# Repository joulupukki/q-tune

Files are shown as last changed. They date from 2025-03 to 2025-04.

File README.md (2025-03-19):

# Q-Tune Chromatic Tuner
This is an in-progress project with the goal of creating a fully open-source chromatic tuner in a standard pedal enclosure for use on pedalboards and based on the ESP32 MCU.

The project uses the Q DSP Library for frequency detection and LVGL 9 for the graphical user interface.

The project now uses a [Waveshare ESP32-S3 Touch 2.8" 240x320](https://www.waveshare.com/product/mcu-tools/development-boards/esp32/esp32-s3-touch-lcd-2.8.htm?sku=27690) screen because of its clean cover glass that's already attached. It helps make a very professional look in a guitar pedal. Currently the capacitive touch isn't being used.

The project first used a Heltec ESP32-S3 with a smaller display, graduated to the Cheap Yellow Display (ESP32-2432S028R/ESP32-WROOM-32), and is now using the Waveshare.

## Setup

1. Install Visual Studio Code
2. Install the Visual Studio Code ESP-IDF extension
3. Configure the ESP-IDF extension by using the express or advanced mode
    - Be sure to choose **v5.3** as the version of ESP-IDF to use
    - You may need to use advanced mode to be able to select the correct location for python3
    - If pip error, navigate to: C:\Espressif\tools\idf-python\3.11.2> and run: python -m ensurepip --upgrade
4. Make sure you have `git` installed
5. Clone this github project
6. From a terminal go into the project and do this:
    ```
    git submodule update --init --recursive
    ```
7. Open the `q-tune` folder in VS Code
8. Set your ESP32 target (esp32s3)
    - Open the Command Palette (Command+Shift+P on a Mac) and select `ESP-IDF: Set Espressif Device Target`
    - Select `esp32s3`
    - Select the `ESP32-S3 chip (via ESP-PROG)` option
9. Select the port to use
    - Plug in your ESP32 dev board and wait for a few seconds
    - Open the Command Palette (Command+Shift+P on a Mac) and select `ESP-IDF: Select Port to Use (COM, tty, usbserial)`
    - Select your port from the drop-down list that appears
    - Windows Only: If you receive an error while trying to locate the serial/COM port that your ESP32 is connected to (or it doesn't show up), you may need to install the driver for the CH340C UART chip that the ESP32-CYD uses for USB communication. The driver is available from the manufacturer here: https://www.wch-ic.com/downloads/CH341SER_ZIP.html
        - After installing the driver and connecting the CYD, re-run the "Select Port" command
10. Attempt to build the software
    - Use the Command Palette and select `ESP-IDF: Build your Project`
11. Assuming step #9 worked, Build and install the software
    - Use the Command Palette and select `ESP-IDF: Build, Flash, and Start a Monitor on your Device`
    - To stop monitoring the output, press Control+T, then X

## Demo

Better smoothing and pre-amp circuit 19 Mar 2025:
Demo Video (https://www.youtube.com/watch?v=D6ZLS6r_rAo)

We're getting closer to releasing the first version. Here's a demo of how it's looking on 13 Mar 2025:
Demo Video (https://youtube.com/live/pk4hbDYdYKE)

Here's a simple demo of how the project is coming along as of 10 Dec 2024:
Demo Video (https://youtu.be/im-Qe8d9LSk)

Here's an older demo, more of a proof-of-concept on a smaller screen using a Heltec ESP32-S3 (20 Aug 2024):

Demo Video (https://youtu.be/XWTicIlTI_k)

## License

This software is licensed under the GNU General Public License (GPL) for open-source use. A commercial license is available for those who wish to use this software in proprietary or closed-source projects. For more details, please contact btimothy [at] gmail [dot] com.

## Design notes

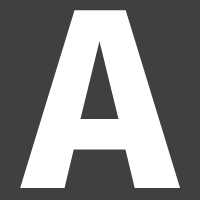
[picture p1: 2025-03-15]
font-images/tuner_font_image_a2x.png

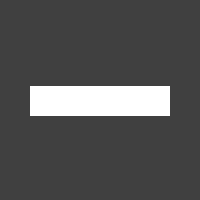
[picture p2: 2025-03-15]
font-images/tuner_font_image_none2x.png

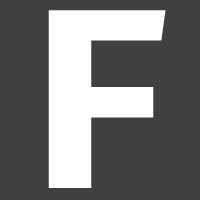
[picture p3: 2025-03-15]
font-images/tuner_font_image_f2x.png

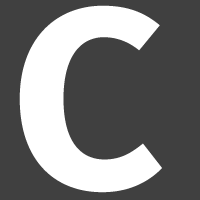
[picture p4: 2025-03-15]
font-images/tuner_font_image_c2x.png

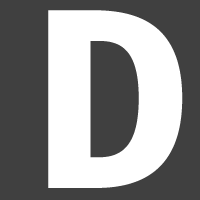
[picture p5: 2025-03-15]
font-images/tuner_font_image_d2x.png

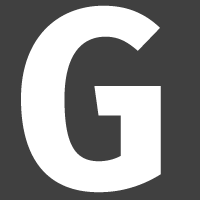
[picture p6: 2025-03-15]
font-images/tuner_font_image_g2x.png

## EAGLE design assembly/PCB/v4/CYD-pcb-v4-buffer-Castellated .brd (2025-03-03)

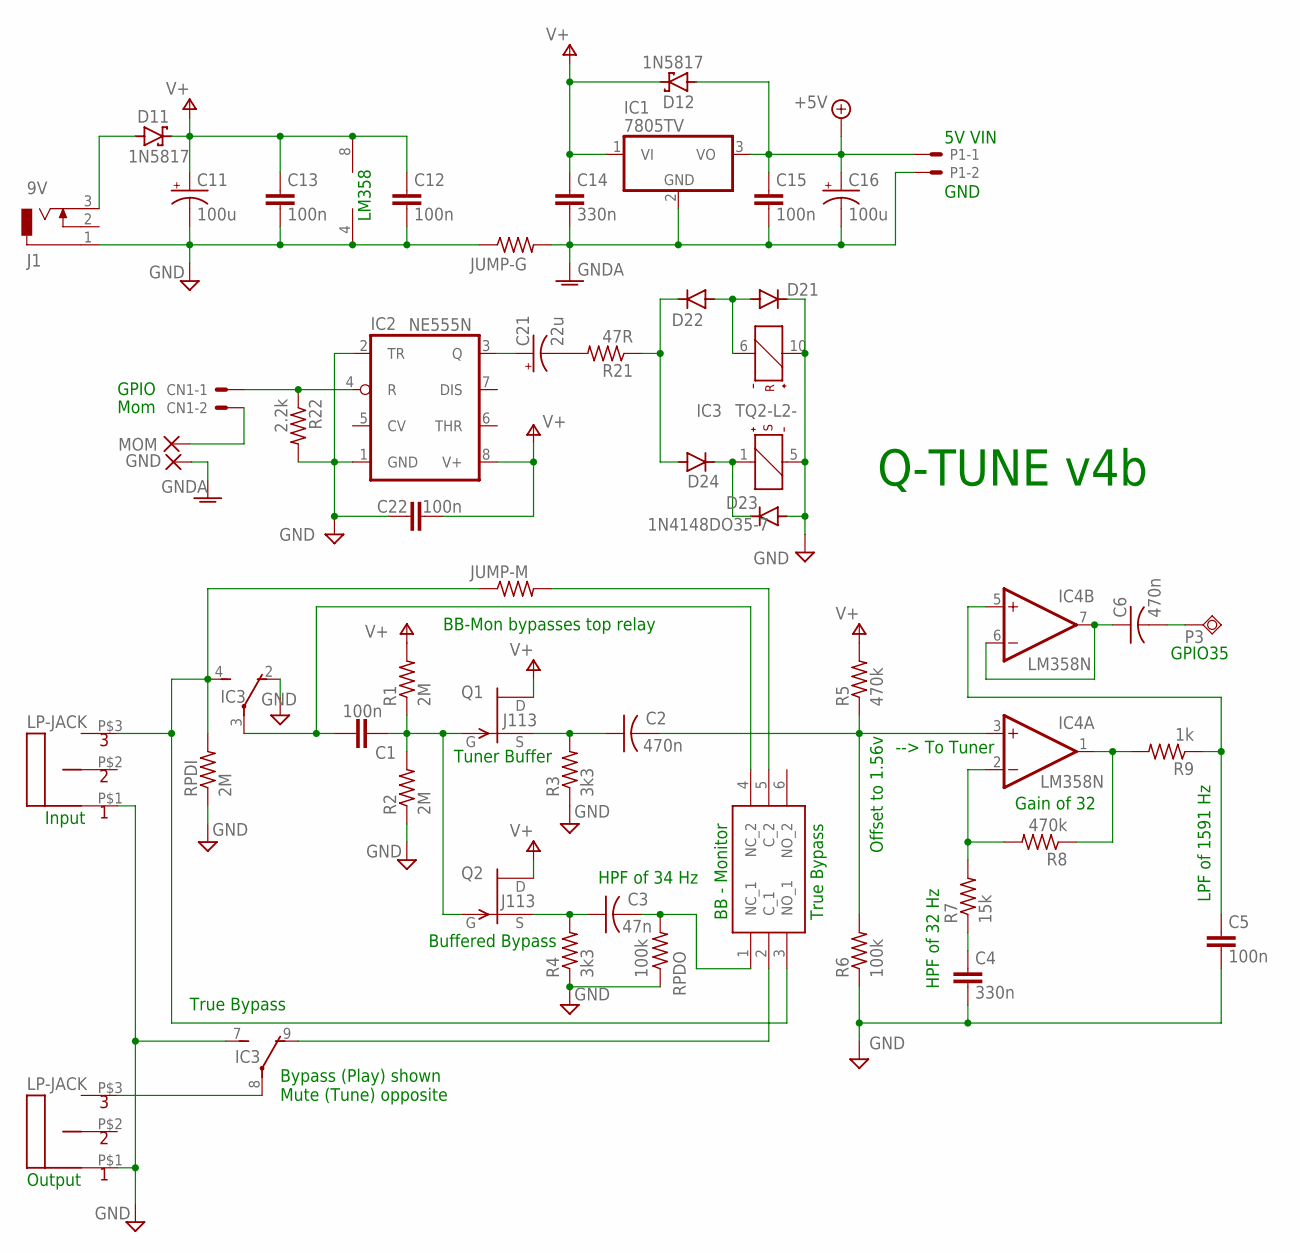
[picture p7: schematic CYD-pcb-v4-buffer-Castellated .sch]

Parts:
C1, C5, C12, C13, C15, C22: 100n; C050-024X044
C2, C6: 470n; C050-035X075
C3: 47n; C050-035X075
C4, C14: 330n; C050-024X044
C11, C16: 100u; E2,5-6
C21: 22u; E2,5-6
CN1: 22-23-2021
D11, D12: 1N5817; DO41-7.6
D21, D22, D23, D24: 1N4148DO35-7; DO35-7
GND: WIREPAD1,6/0,9; 1,6/0,9
IC1: 7805TV; TO220V
IC2: NE555N; DIL08
IC3: TQ2-L2-; TQ2
IC4: LM358N; DIL08
INPUTJACK: LPJACK-DEVICE; LPJACK-FOOTPRINT
J1: 9V; DCJ0303
JUMP-G: *; 0207/7
JUMP-M: 1; 0207/7
MOM: WIREPAD1,6/0,9; 1,6/0,9
OUTPUTJACK: LPJACK-DEVICE; LPJACK-FOOTPRINT
P1: 22-23-2021
P3: TPSQPAD1-13Y; P1-13Y
Q1, Q2: J113; TO92-
R1, R2: 2M; 0207/7
R3, R4: 3k3; 0207/7
R5, R8: 470k; 0207/7
R6: 100k; 0207/7
R7: 15k; 0207/7
R9: 1k; 0207/7
R21: 47R; 0207/7
R22: 2.2k; 0207/7
RPDI: 2M; 0207/7
RPDO: 100k; 0207/7
SW1: JS202011AQN

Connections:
+5V: C15.1, C16.+, D12.A, IC1.3 (VO), P1.1
GND: C4.2, C5.2, C11.-, C12.2, C13.2, C22.1, D21.C, D23.A, IC2.1 (GND), IC2.2 (TR), IC3.2 (O), IC3.5 (-), IC3.7 (S), IC3.10 (+), IC4.4 (V-), INPUTJACK.P$1 (1), J1.1, JUMP-G.1, OUTPUTJACK.P$1 (1), R2.1, R3.1, R4.1, R6.1, R22.2, RPDI.1, RPDO.1
GNDA: C14.2, C15.2, C16.-, GND.1, IC1.2 (GND), JUMP-G.2, P1.2
unnamed: CN1.1, IC2.4 (R), R22.1
unnamed: C3.2, RPDO.2, SW1.1 (NC_1)
unnamed: C2.1, Q1.2 (S), R3.2
unnamed: C2.2, IC4.3 (+IN), R5.1, R6.2
unnamed: IC4.2 (-IN), R7.2, R8.2
unnamed: IC4.1 (OUT), R8.1, R9.2
unnamed: D22.C, D24.A, R21.1
unnamed: C6.1, IC4.6 (-IN), IC4.7 (OUT)
unnamed: CN1.2, MOM.1
unnamed: D11.A, J1.3
unnamed: C4.1, R7.1
unnamed: D23.C, D24.C, IC3.1 (+)
unnamed: D21.A, D22.A, IC3.6 (-)
unnamed: C1.2, IC3.3, SW1.4 (NC_2)
unnamed: C21.+, IC2.3 (Q)
unnamed: C21.-, R21.2
unnamed: C5.1, IC4.5 (+IN), R9.1
unnamed: C1.1, Q1.1 (G), Q2.1 (G), R1.1, R2.2
unnamed: C3.1, Q2.2 (S), R4.2
unnamed: IC3.8, OUTPUTJACK.P$3 (3)
unnamed: IC3.9 (O), SW1.2 (C_1)
unnamed: JUMP-M.2, SW1.5 (C_2)
unnamed: C6.2, P3.TP
unnamed: IC3.4 (S), INPUTJACK.P$3 (3), JUMP-M.1, RPDI.2, SW1.3 (NO_1)
V+: C11.+, C12.1, C13.1, C14.1, C22.2, D11.C, D12.C, IC1.1 (VI), IC2.8 (V+), IC4.8 (V+), Q1.3 (D), Q2.3 (D), R1.2, R5.2

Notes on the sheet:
Input
Output
Mom
GPIO
GND
5V VIN
Gain of 32
HPF of 32 Hz
LPF of 1591 Hz
Offset to 1.56v
--> To Tuner
Q-TUNE v4b
GPIO35
LM358
Tuner Buffer
Buffered Bypass
Bypass (Play) shown Mute (Tune) opposite
True Bypass
BB - Monitor
BB-Mon bypasses top relay
HPF of 34 Hz

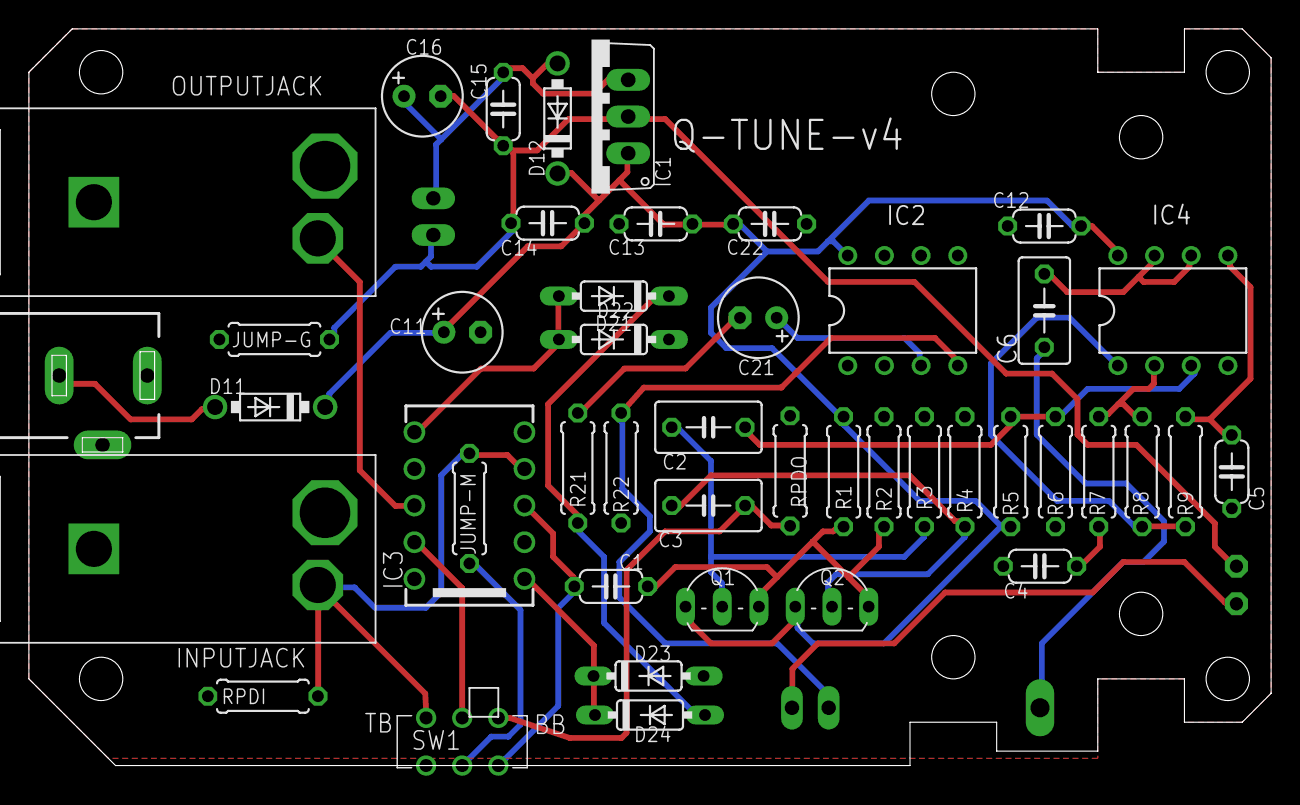
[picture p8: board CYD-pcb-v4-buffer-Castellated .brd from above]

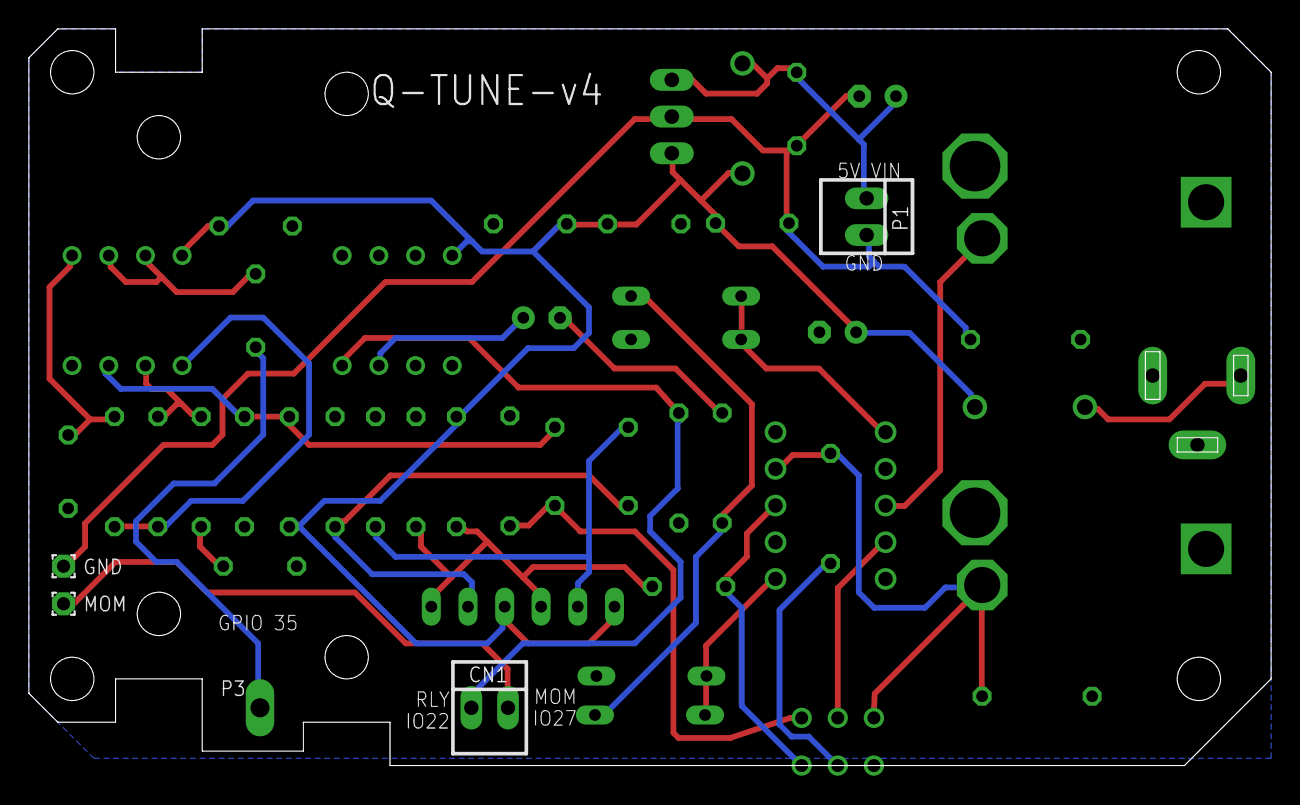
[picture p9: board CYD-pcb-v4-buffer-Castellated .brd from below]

Board: 2 copper layers, 86.0 x 51.0 mm, 50 parts (4 on the bottom side), 28 nets.

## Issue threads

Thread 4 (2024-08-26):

Add support for a mode button/switch

joulupukki, 2024-08-26:
The tuner should be able to support multiple "modes" of tuning. This is mostly for the UI.

Two ways to implement this from a hardware perspective:
1. Use a three-way switch that's hooked up to three different GPIO pins. Depending on the switches orientation the software could (at startup) use the specified mode.
2. Use a momentary button that would cycle through the different available modes. To prevent accidental press, this could be implemented as a long press mechanism

Some modes that could be nice:
1. Normal tuning mode (what we already have)
2. Raw mode: gives just basic frequency, note, and cents reading
3. Debug mode: continuously spits out info about voltage reading, intermediate values (after applying filters etc), frequency, cents, etc.
4. Additional UI modes in the future (like simulated strobe mode or just different UI layouts)

The code needs to be changed so that it can read the value of the switch at startup and/or during each loop. Also, to keep memory consumption low, UI elements for each mode (and processing) should be torn down as needed.

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
joulupukki, 2024-12-07:
Closing this one because we're going to implement it in a different way.

Closed 2024-12-07.

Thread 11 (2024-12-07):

Add a smoothing function on the detected frequency so the UI doesn't jump around as much

joulupukki, 2024-12-07:
The ADC sampling happens at 48kHz and as soon as we detect a frequency, we're making it available to the UI. The UI updates every 100ms. The smoothing we currently have isn't sufficient and it might be nice to have an additional smoothing on the frequency output so by the time it reaches the UI, the jumps aren't as drastic or as much.

The key here is to see if we can make it so you can really tune within 0.02 cents and visually see that in the UI.

One of the things we may be up against is that the ESP32 ADC isn't the best compared with other SOCs out there. But, this is all part of the "fun" challenge of using a readily-available and inexpensive SOC.

joulupukki, 2024-12-08:
I did a little bit of work on this Saturday, Dec 7. The latest in `main` as of right now is fairly decent, though I think it can be still improved.

joulupukki, 2025-02-10:
> There’s an algorithm, not sure what it’s called, where you sample an odd number of readings, order the readings, and only use the reading in the middle of the readings. I’d like to try that on the output of the frequency readings to see if that helps smooth things a bit more.

It's called a Median Filter and I've been experimenting with it. I think it slightly improves how Q-Tune works.

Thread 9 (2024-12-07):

Try out using lv_menu instead of buttons for the settings menu

joulupukki, 2024-12-07:

joulupukki, 2024-12-07:
So far this is not going great. Even after increasing the stack size available to LVGL and using the most basic example from the LVGL documentation it still crashes regularly with an overflow error.

joulupukki, 2024-12-10:
Need to revisit this now that we have the device running at 240MHz to see if this still causes issues. Running at this faster speed has prevented the previous crashes with the note name label we were seeing.

Closed 2025-02-08.

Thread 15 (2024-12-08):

Add synchronization around the current_frequency variable (shared between both cores)

joulupukki, 2024-12-08:
The `current_frequency` global variable is the main means of communication between the two cores and it’s possible that some of the crashes that we’re experiencing could be caused by this.

Some ideas to try: https://chatgpt.com/share/67554351-7c18-8010-bc82-93a870aeeb30

Another thing to look into is the LVGL setting for sprintf. Right now, in order to make the frequency and cents measurements show up in the UI we’ve got an sdkconfig setting that doesn’t use the built-in LVGL string formatting. We may also want to look at using LVGL’s sprintf and see if *that* also reduces the number of crashes that currently happen.

joulupukki, 2024-12-08:
Maybe what needs to happen is to create a new “globals.h” file that has all of the app-wide global variables in it and also the functions that synchronize them? The other variable that needs to be there is the one that indicates that either tuning is paused or that the user settings are showing (so the pitch detection doesn’t have to run during that time). Maybe the overall “mode” of the tuner (bypass/standby/tuning/etc).

joulupukki, 2024-12-08:
Implemented 8 Dec 2024.

Closed 2024-12-08.

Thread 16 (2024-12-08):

Add support for the momentary foot switch and bypass relay control

joulupukki, 2024-12-08:
I will add more details to this later but, the app needs to read when the footswitch closes and, based on user settings, send a signal out to the latching relay to open/close. It will also need to tell the UI to pause/go into standby mode/etc.

TODO: Document what GPIO will be used for the footswitch input and the relay output.

I’m thinking that right now the footswitch reading and relay control will happen on Core 0 (where we’re doing all of the LVGL stuff) and not on Core 1 (where we’re doing ADC reading of the analog input signal).

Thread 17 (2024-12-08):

Add new menu setting inside “Tuner” that sets the bypass/standby mode

joulupukki, 2024-12-08:
Inside the Tuner/Tuning menu, we need a “Bypass Mode” or “Standby Mode” options where you can choose:

1. Mute during tuning
2. Monitor during tuning (tuning is still active)

If “Mute while tuning” is selected, we need to also figure out what to show on the screen:
1. Blank
2. Some sort of screensaver
3. Picture
4. Words? Set list? Etc.?

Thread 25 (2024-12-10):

See if it's possible to switch the main note display from text to an image

joulupukki, 2024-12-10:
For whatever reason, I'm still seeing glitches with displaying the note. It will have garbled stuff occasionally. Can an image be used instead? Can images be template images that get colorized?

joulupukki, 2024-12-10:
Still need to try image recoloring for maybe even a better experience. I still see an occasional '?' show up where the note name label should be – even for a fraction of a second.

joulupukki, 2024-12-10:
I've loaded in the [Fira Mono](https://fonts.google.com/specimen/Fira+Mono?preview.text=A%20B%20C%20D%20E%20F%20G%20%23%20%E2%80%93) font by creating PNG images of each note and then using LVGL's online image creator. Need to still do some testing.

I also bumped the memory cache size to 327680.

joulupukki, 2024-12-11:
This is now implemented with this pull request: https://github.com/joulupukki/esp32-chromatic-tuner/pull/28

Closed 2024-12-11.

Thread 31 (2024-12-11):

Touches on the CYD screen can be off – need to add a touch screen calibration option

joulupukki, 2024-12-11:
The touches on my CYD are slightly off. That means that it’s possible others will experience that too. I think that means we need to add a calibration option to the Display user settings menu.

In a quick search I discovered this project. It may have something that’d help: https://github.com/jakpaul/lvgl_touch_calibration

joulupukki, 2024-12-11:
When the software first loads, it should check to see if calibration info has been stored in Non-Volatile Storage (NVS). If it hasn’t, it should open the settings screen to calibrate it right away. Of course, give the user an option to skip it if they really want.

joulupukki, 2025-02-05:
While researching code to prevent noise I came across something (should have written it down) that this isn't actually needed with CYD. Keep an eye on it and this is something we may do in the future, but not for now.

joulupukki, 2025-02-11:
If this needs to happen in the future, this might be useful to reference: https://github.com/xperiments-in/xtouch/blob/main/src/devices/2.8/touch.h

Closed 2025-02-05.

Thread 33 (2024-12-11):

Figure out how to create a downloadable tool or method for installing firmware updates

joulupukki, 2024-12-11:
Eventually a person (non-technical) should be able to download firmware updates and install it onto the tuner without needing to install extra software like Visual Studio Code/etc. This GitHub Issue is a placeholder for doing the investigatory work and building such a tool and recommending a good release process.

joulupukki, 2025-02-08:
I did a little bit of research yesterday about this and I think what we’ll want to do is an over-the-air (OTA) update. To update the firmware you would:

1. Go into Q-Tune’s user settings
2. Go into the About menu
3. Select a Firmware Update option
4. Confirm the selection
5. The Q-Tune would reboot and would turn on Wi-Fi and broadcast a new Wi-Fi network, `q-tune-xyz` as an example with a password. Ideally, we’d figure out a way to show the network name and password on the screen.
6. You’d download the firmware update file, `q-tune-x.y.z.bin`
7. You’d then connect to the `q-tune-xyz` Wi-Fi network
8. You’d then launch a browser on your computer and go to the `q-tune.local` URL
9. You’d upload the `q-tune-x.y.z.bin` file
10. You’d click the Update button on the web page
11. Q-Tune would then install that `.bin` file and reboot into normal tuning mode with the update

joulupukki, 2025-02-10:
Turns out that the firmware for Q-Tune is too large to enable the Wi-Fi library in conjunction with it and LVGL so doing what I thought of earlier isn't going to work.

However, if we do a web-based updater, it should work. For example, just like this site: https://esphome.github.io/esp-web-tools/

joulupukki, 2025-03-25:
I have an update-installer.sh script that updates the installer but what we really need is something to support installing older versions.

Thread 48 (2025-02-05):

5kHz noise in the audio

joulupukki, 2025-02-05:
The LCD backlight code is using PWM at 5kHz and it can be heard in the audio output.

Closed 2025-02-05.

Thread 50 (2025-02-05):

Control user settings with foot switch

joulupukki, 2025-02-05:
We are planning to use a cover glass/lens to do a few different things:

1. Protect the CYD screen
2. Make a more professional looking screen in the finished product
3. Make the pedal a bit more weather/drink resistant (at least from the top)

Because of this, we will no longer be using the touch panel feature and instead need to control all of user settings from a single footswitch button.

Things that need to be done:

- [ ] Don't even initialize the touch panel (for this one we would wait and see as this may be dependent on the cover glass mounting).
- [x] Experiment with either using a long press to open user settings _or_ only going into user settings when powering on the tuner and the footswitch is depressed. Choose whichever one seems most reliable and go with it. It may be that we want to use long press later on for controlling a timer, so maybe prefer the startup hold?
- [x] Modify the menu system so there is a cursor/indicator on what is currently selected (a selection mechanism)
- [x] Use the footswitch to navigate the menu. Single press advances to the next item in the list. Double-press activates the currently-selected item. Long-press exits the menu if at the top level or going back one level in the menu hierarchy.
- [ ] Change some of the menu items to be more conducive to this new navigation. First see if it’s possible to navigate the different items (display brightness slider, tuner threshold rolling picker, advanced debugging items). If it’s not apparent right away, change those menus to use standard buttons and/or radio buttons.

Closed 2025-02-07.

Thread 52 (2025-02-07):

Before release, disable touch panel initialization

joulupukki, 2025-02-07:
We're using the foot switch to control navigation of user settings and the touch panel will no longer be used. It may be helpful in development mode, but the LCD will be covered by a cover lens.

joulupukki, 2025-03-16:
Touch is currently commented out and not being added.

joulupukki, 2025-04-21:
Closing this because we now have a new feature request to add capacitive touch with the new Waveshare ESP32 2.8" Touch.

Closed 2025-04-21.

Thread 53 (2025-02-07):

Remove the settings gear icon/button from the tuning screen before release

joulupukki, 2025-02-07:
We'll ship without the touch panel being used so there's no reason to have the settings button. Settings can be accessed with a long press of the foot switch.

joulupukki, 2025-03-25:
This is commented out now. If we restore touch capabilities we can always re-enable it.

Closed 2025-03-25.

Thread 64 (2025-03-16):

Attempt to use RMT instead of ADC Continuous reading for frequency detection

joulupukki, 2025-03-16:
It might be possible to use RMT instead of ADC measurements since the pitch detection algorithm we're using is just counting zero crossings. This is an issue to track that work.

RMT API Reference: https://docs.espressif.com/projects/esp-idf/en/v5.3.2/esp32/api-reference/peripherals/rmt.html

joulupukki, 2025-03-23:
Shelving this for now. Existing ADC is working well enough I don't think this is needed.

Closed 2025-03-23.

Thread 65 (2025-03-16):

Enhancement: Add support for the capacitive touch screen

joulupukki, 2025-03-16:
The project recently switched to use the Waveshare ESP32-S3 Touch 2.8" (240x320) and it has a capacitive touch panel. I've done some of the work at porting it over but something isn't quite right. The tuner can be controlled from the single foot switch momentary button but it might be interesting to get the touch controller fully working for easier setup menu navigation.

When I had it partially working with esp_lvgl_port it would act like it might accept a touch but would then crash.

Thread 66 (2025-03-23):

Add support for setting True Bypass & Buffered Bypass with a 2nd relay switch

joulupukki, 2025-03-23:
Use GPIO_NUM_15 for controlling a second TQ2-L2-5V relay. Add this as a user setting. When in buffered bypass mode, GPIO_NUM_15 should be set to ON which will send 3.3V. When power is cut to the pedal, it should automatically reset to the default mode (true bypass) – which isn't really a supported "feature" but it happens to work out well that way.

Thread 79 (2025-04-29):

Prep Note Quiz for release

joulupukki, 2025-04-29:
- [ ] Change the included tuner so it uses something similar to how Rocksmith’s small tuner works with a circle around the note and cents on left and right
- [ ] Show “Play now” and “Up next” on the notes
- [ ] Adapt so it functions well in landscape mode
- [ ] Revisit the colors
- [ ] See if there’s a way to give some sort of cool feedback when the target note is played. Maybe animate the new note into place?

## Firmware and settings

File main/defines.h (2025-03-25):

/*
 * Copyright (c) 2024 Boyd Timothy. All rights reserved.
 *
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
 * SPDX-License-Identifier: GPL-3.0-or-later
 */
#if !defined(TUNER_GLOBAL_DEFINES)
#define TUNER_GLOBAL_DEFINES

#include "driver/gpio.h"
#include "hal/adc_types.h"

typedef enum {
    NOTE_C = 0,
    NOTE_C_SHARP,
    NOTE_D,
    NOTE_D_SHARP,
    NOTE_E,
    NOTE_F,
    NOTE_F_SHARP,
    NOTE_G,
    NOTE_G_SHARP,
    NOTE_A,
    NOTE_A_SHARP,
    NOTE_B,
    NOTE_NONE
} TunerNoteName;

inline const char *name_for_note(TunerNoteName note) { 
    switch (note) {
        case NOTE_C:
            return "C";
        case NOTE_C_SHARP:
            return "C#";
        case NOTE_D:
            return "D";
        case NOTE_D_SHARP:
            return "D#";
        case NOTE_E:
            return "E";
        case NOTE_F:
            return "F";
        case NOTE_F_SHARP:
            return "F#";
        case NOTE_G:
            return "G";
        case NOTE_G_SHARP:
            return "G#";
        case NOTE_A:
            return "A";
        case NOTE_A_SHARP:
            return "A#";
        case NOTE_B:
            return "B";
        case NOTE_NONE:
            return "-";
        default:
            return "Unknown";
    }
}

typedef struct {
    float frequency;
    float cents;
    float targetFrequency;
    TunerNoteName targetNote;
    int targetOctave;
} FrequencyInfo;

typedef enum : uint8_t {
    tunerBypassTypeTrue = 0,
    tunerBypassTypeBuffered,
} TunerBypassType;

//
// RTOS Queues
//

// The pitch detector task will always write the latest value of detection on
// the queue. Use a length of 1 so we can use xQueueOverwrite and xQueuePeek so
// the very latest frequency info is always available to anywhere.

#define FREQUENCY_QUEUE_LENGTH 1
#define FREQUENCY_QUEUE_ITEM_SIZE sizeof(FrequencyInfo)

#define TUNER_STATE_QUEUE_LENGTH 1
#define TUNER_STATE_QUEUE_ITEM_SIZE sizeof(uint8_t)

//
// Foot Switch and Relay (GPIO)
//
#define FOOT_SWITCH_GPIO                GPIO_NUM_44 // RXD on EBD2
#define BYPASS_RELAY_GPIO               GPIO_NUM_43 // TXD on EBD2
#define BYPASS_TYPE_RELAY_GPIO          GPIO_NUM_15 // True Bypass (3.3V "On" state) or Buffered Bypass (0V "Off" state)

#define LONG_PRESS_TIME_MS              1000 // milliseconds
#define DOUBLE_PRESS_TIME_MS            250 // milliseconds
#define DEBOUNCE_TIME_MS                50 // milliseconds

//
// LCD
//
#define LCD_H_RES                       240
#define LCD_V_RES                       320
#define LCD_BITS_PIXEL                  16
#define LCD_BUF_LINES                   30
#define LCD_DOUBLE_BUFFER               1
#define LCD_DRAWBUF_SIZE                (LCD_H_RES * LCD_BUF_LINES)
#define LCD_MIRROR_X                    (true)
#define LCD_MIRROR_Y                    (false)

//
// Default User Settings
//
#define DEFAULT_INITIAL_STATE           ((TunerState) tunerStateTuning)
#define DEFAULT_BYPASS_TYPE             ((TunerBypassType) tunerBypassTypeTrue)
#define DEFAULT_STANDBY_GUI_INDEX       (0)
#define DEFAULT_TUNER_GUI_INDEX         (0)
#define DEFAULT_IN_TUNE_CENTS_WIDTH     ((uint8_t) 2)
#define DEFAULT_MONITORING_MODE         (0)
#define DEFAULT_NOTE_NAME_PALETTE       ((lv_palette_t) LV_PALETTE_NONE)
#define DEFAULT_DISPLAY_ORIENTATION     ((TunerOrientation) orientationNormal);
#define DEFAULT_EXP_SMOOTHING           ((float) 0.09)
#define DEFAULT_ONE_EU_BETA             ((float) 0.003)
#define DEFAULT_NOTE_DEBOUNCE_INTERVAL  ((float) 115.0)
#define DEFAULT_USE_1EU_FILTER_FIRST    (true)
// #define DEFAULT_MOVING_AVG_WINDOW       ((float) 100)
#define DEFAULT_DISPLAY_BRIGHTNESS      ((uint8_t) 7) // equates to 80% brightness because we're storing the value as a 0-based integer (0 - 10%, 1 - 20%, etc.)

//
// Pitch Detector Related
//
#define TUNER_ADC_UNIT                  ADC_UNIT_2
// #define TUNER_ADC_CHANNEL               ADC_CHANNEL_4 // GPIO15 - According to the ESP32-S3 datasheet, GPIO15 is a strapping pin and shouldn't be used
#define TUNER_ADC_CHANNEL               ADC_CHANNEL_7 // GPIO18
#define TUNER_ADC_CONV_MODE             ADC_CONV_SINGLE_UNIT_2
#define _TUNER_ADC_UNIT_STR(unit)       #unit
#define TUNER_ADC_UNIT_STR(unit)        _TUNER_ADC_UNIT_STR(unit)
#define TUNER_ADC_ATTEN                 ADC_ATTEN_DB_12
#define TUNER_ADC_BIT_WIDTH             12
#define TUNER_ACD_FILTER_COEFF          ADC_DIGI_IIR_FILTER_COEFF_64

// #if CONFIG_IDF_TARGET_ESP32 || CONFIG_IDF_TARGET_ESP32S2
// #define TUNER_ADC_OUTPUT_TYPE             ADC_DIGI_OUTPUT_FORMAT_TYPE1
// #define TUNER_ADC_GET_CHANNEL(p_data)     ((p_data)->type1.channel)
// #define TUNER_ADC_GET_DATA(p_data)        ((p_data)->type1.data)
// #else
#define TUNER_ADC_OUTPUT_TYPE             ADC_DIGI_OUTPUT_FORMAT_TYPE2
#define TUNER_ADC_GET_CHANNEL(p_data)     ((p_data)->type2.channel)
#define TUNER_ADC_GET_DATA(p_data)        ((p_data)->type2.data)
// #endif

// CYD @ 48kHz
// #define TUNER_ADC_FRAME_SIZE            1024
// #define TUNER_ADC_BUFFER_POOL_SIZE      4096
// #define TUNER_ADC_SAMPLE_RATE           (48 * 1000) // 48kHz

// EBD4 @ 5kHz
// #define TUNER_ADC_FRAME_SIZE            (SOC_ADC_DIGI_DATA_BYTES_PER_CONV * 64)
// #define TUNER_ADC_BUFFER_POOL_SIZE      (TUNER_ADC_FRAME_SIZE * 4)
// #define TUNER_ADC_SAMPLE_RATE           (5 * 1000) // 5kHz 

// EBD2 @ 5kHz
#define TUNER_ADC_FRAME_SIZE            (SOC_ADC_DIGI_DATA_BYTES_PER_CONV * 64)
#define TUNER_ADC_BUFFER_POOL_SIZE      (TUNER_ADC_FRAME_SIZE * 4)
#define TUNER_ADC_SAMPLE_RATE           (5 * 1000) // 5kHz

/*
    ADC_DIGI_IIR_FILTER_COEFF_2,     ///< The filter coefficient is 2
    ADC_DIGI_IIR_FILTER_COEFF_4,     ///< The filter coefficient is 4
    ADC_DIGI_IIR_FILTER_COEFF_8,     ///< The filter coefficient is 8
    ADC_DIGI_IIR_FILTER_COEFF_16,    ///< The filter coefficient is 16
    ADC_DIGI_IIR_FILTER_COEFF_64,    ///< The filter coefficient is 64
*/

// EBD2 @ 3.3kHz with ADS1015 (External ADC)
// #define TUNER_ADC_SAMPLE_RATE               (3.3 * 1000) // 3.3kHz 
// #define TUNER_ADC_BUFFER_SIZE               300
// #define TUNER_ADC_NUM_OF_BUFFERS            6
// #define TUNER_ADC_ALERT_PIN                 GPIO_NUM_18
// #define TUNER_ADC_SAMPLE_INTERVAL           (1000000 / TUNER_ADC_SAMPLE_RATE) // microseconds to read one sample

/// @brief This factor is used to correct the incoming frequency readings on ESP32-WROOM-32 (which CYD is). This same weird behavior does not happen on ESP32-S2 or ESP32-S3.
// #define WEIRD_ESP32_WROOM_32_FREQ_FIX_FACTOR    1.2222222223 // 11/9 but using 11/9 gives completely incorrect results. Weird.
// #define WEIRD_ESP32_WROOM_32_FREQ_FIX_FACTOR    1 // ESP32-S3 does not need this correction.

// HELTEC @ 20kHz
// #define TUNER_ADC_FRAME_SIZE            (SOC_ADC_DIGI_DATA_BYTES_PER_CONV * 256)
// #define TUNER_ADC_BUFFER_POOL_SIZE      (TUNER_ADC_FRAME_SIZE * 16)
// #define TUNER_ADC_SAMPLE_RATE           (20 * 1000) // 20kHz

// Original HELTEC
// #define TUNER_ADC_FRAME_SIZE            (SOC_ADC_DIGI_DATA_BYTES_PER_CONV * 64)
// #define TUNER_ADC_BUFFER_POOL_SIZE      (TUNER_ADC_FRAME_SIZE * 4)
// #define TUNER_ADC_SAMPLE_RATE           (5 * 1000) // 5kHz

// If the difference between the minimum and maximum input values
// is less than this value, discard the reading and do not evaluate
// the frequency. This should help cut down on the noise from the
// OLED and only attempt to read frequency information when an
// actual input signal is being read.
// #define TUNER_READING_DIFF_MINIMUM      80
// #define TUNER_READING_DIFF_MINIMUM      100
#define TUNER_READING_DIFF_MINIMUM      600

//
// Smoothing
//

// 1EU Filter
#define EU_FILTER_ESTIMATED_FREQ        110

#define EU_FILTER_MIN_CUTOFF            1.0
#define EU_FILTER_BETA                  ((float) 0.05)
#define EU_FILTER_DERIVATIVE_CUTOFF     1.0

#define EU_FILTER_MIN_CUTOFF_2          0.5
#define EU_FILTER_BETA_2                ((float) 0.05)
#define EU_FILTER_DERIVATIVE_CUTOFF_2   1.0

// Exponential Smoothing
#define EXP_SMOOTHING                  ((float) 0.5)

//
// GUI Related
//

#define A4_FREQ                         440.0
#define CENTS_PER_SEMITONE              100

#define INDICATOR_SEGMENTS              100 // num of visual segments for showing tuning accuracy

#define GEAR_SYMBOL "\xEF\x80\x93"

//
// When the pitch stops being detected, the note can fade out. This is how long
// that animation is set to run for.
#define LAST_NOTE_FADE_INTERVAL_MS  2000

#endif

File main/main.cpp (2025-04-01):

/*
 * Copyright (c) 2024 Boyd Timothy. All rights reserved.
 *
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
 * SPDX-License-Identifier: GPL-3.0-or-later
 */
#include "esp_log.h"
#include "freertos/FreeRTOS.h"
#include "freertos/queue.h"
#include "esp_adc/adc_continuous.h"
#include "esp_timer.h"

#include "defines.h"
#include "user_settings.h"
#include "tuner_controller.h"
#include "tuner_gui_task.h"

extern "C" { // because these files are C and not C++
    #include "I2C_Driver.h"
}

extern void gpio_task(void *pvParameter);
extern void tuner_gui_task(void *pvParameter);
extern void pitch_detector_task(void *pvParameter);

TunerController *tunerController;
UserSettings *userSettings;

TaskHandle_t gpioTaskHandle;
TaskHandle_t detectorTaskHandle;

QueueHandle_t frequencyQueue;

/// Queue to keep track of the bypass type state.
QueueHandle_t bypassTypeQueue;

/// Use this to temporarily enable bypass mode when showing the bypass settings
/// screen so people can hear the difference between true bypass and buffered
/// bypass. The value passed is either a 0 (not in the bypass type settings
/// screen) or a 1 (in the bypass type settings screen).
QueueHandle_t bypassTypeSettingsScreenQeuue;

/* GPIO PINS

P3:
GND - Not used
GPIO 35 (ADC1_CH7) - Input of the amplified guitar signal here
GPIO 22 - Control signal to the non-latching relay
GPIO 21 - This is not available since it's always ON when the LCD backlight is on

CN1:
GND - Not used
GPIO 22 - Same as P3
GPIO 27 - Momentary foot switch input
3V3 - Not used

*/

static const char *TAG = "TUNER";

void tuner_state_will_change_cb(TunerState old_state, TunerState new_state) {
    // ESP_LOGI(TAG, "tuner_state_will_change_cb: %d > %d", old_state, new_state);
}

void tuner_state_did_change_cb(TunerState old_state, TunerState new_state) {
    // Suspend and resume tasks as needed.
    switch (new_state) {
    case tunerStateSettings:
        vTaskSuspend(detectorTaskHandle);
        break;
    case tunerStateStandby:
        if (!userSettings->monitoringMode) {
            vTaskSuspend(detectorTaskHandle);
        }
        break;
    case tunerStateTuning:
        vTaskResume(detectorTaskHandle);
        break;
    case tunerStateBooting:
        break;
    }
}

void footswitch_pressed_cb(FootswitchPress press) {
    TunerState current_state = tunerController->getState();
    switch (current_state) {
    case tunerStateStandby:
        break;
    case tunerStateTuning:
        if (press == footswitchLongPress) {
            tunerController->setState(tunerStateSettings);
        }
        break;
    case tunerStateSettings:
        userSettings->footswitchPressed(press);
        break;
    case tunerStateBooting:
        break;
    }
}

void user_settings_will_show_cb() {
}

void user_settings_changed_cb() {
    user_settings_updated();
}

/// @brief Called right before user settings exits back to the main tuner UI.
void user_settings_will_exit_cb() {
}

extern "C" void app_main() {
    
    // Create the info-passing queues before loading settings so they can be used
    
    frequencyQueue = xQueueCreate(FREQUENCY_QUEUE_LENGTH, FREQUENCY_QUEUE_ITEM_SIZE);
    if (frequencyQueue == NULL) {
        ESP_LOGE(TAG, "Frequency Queue creation failed!");
    } else {
        ESP_LOGI(TAG, "Frequency Queue created successfully!");
    }

    bypassTypeQueue = xQueueCreate(1, sizeof(TunerBypassType));
    if (bypassTypeQueue == NULL) {
        ESP_LOGE(TAG, "Bypass Type Queue creation failed!");
    } else {
        ESP_LOGI(TAG, "Bypass Type Queue created successfully!");
    }

    bypassTypeSettingsScreenQeuue = xQueueCreate(1, sizeof(bool));
    if (bypassTypeSettingsScreenQeuue == NULL) {
        ESP_LOGE(TAG, "Bypass Type Settings Screen Queue creation failed!");
    } else {
        ESP_LOGI(TAG, "Bypass Type Settings Screen Queue created successfully!");
    }

    // Initialize NVS (Persistent Flash Storage for User Settings)
    userSettings = new UserSettings(user_settings_will_show_cb, user_settings_changed_cb, user_settings_will_exit_cb);
    user_settings_changed_cb(); // Calling this allows the pitch detector and tuner UI to initialize properly with current user

    // I2C_Init();

    tunerController = new TunerController(tuner_state_will_change_cb, tuner_state_did_change_cb, footswitch_pressed_cb);

    // // Start the GPIO Task
    xTaskCreatePinnedToCore(
        gpio_task,          // callback function
        "gpio",             // debug name of the task
        4096,               // stack depth (no idea what this should be)
        NULL,               // params to pass to the callback function
        0,                  // ux priority - higher value is higher priority
        &gpioTaskHandle,    // handle to the created task - we don't need it
        0                   // Core ID - since we're not using Bluetooth/Wi-Fi, this can be 0 (the protocol CPU)
    );

    // Start the Display Task
    xTaskCreatePinnedToCore(
        tuner_gui_task,     // callback function
        "tuner_gui",        // debug name of the task
        // 16384,              // stack depth (no idea what this should be)
        32768,              // stack depth (no idea what this should be)
        NULL,               // params to pass to the callback function
        1,                  // ux priority - higher value is higher priority
        NULL,               // handle to the created task - we don't need it
        0                   // Core ID - since we're not using Bluetooth/Wi-Fi, this can be 0 (the protocol CPU)
    );

    // Start the Pitch Reading & Detection Task
    xTaskCreatePinnedToCore(
        pitch_detector_task,    // callback function
        "pitch_detector",       // debug name of the task
        4096,                   // stack depth (no idea what this should be)
        NULL,                   // params to pass to the callback function
        10,                     // This has to be higher than the tuner_gui task or frequency readings aren't as accurate
        &detectorTaskHandle,    // handle to the created task - we don't need it
        1                       // Core ID
    );
}

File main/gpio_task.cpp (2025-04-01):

/*
 * Copyright (c) 2024 Boyd Timothy. All rights reserved.
 *
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
 * SPDX-License-Identifier: GPL-3.0-or-later
 */
#include "gpio_task.h"

#include "defines.h"
#include "tuner_controller.h"
#include "user_settings.h"

#include "lvgl.h"
// #include "esp_lvgl_port.h"
#include "esp_log.h"
#include "freertos/FreeRTOS.h"
#include "esp_timer.h"

// #include "multi_button.h"

static const char *TAG = "GPIO";

extern TunerController *tunerController;
extern QueueHandle_t bypassTypeQueue;
extern QueueHandle_t bypassTypeSettingsScreenQeuue;

// Keep track of the relay states so the app doesn't have to set them over and over
// making calls to set it over and over.
uint32_t current_bypass_relay_level = 0; // Off at launch
uint32_t current_bypass_type_relay_level = 0; // Off at launch

int footswitch_last_state = 1; // Assume initial state is open (active-high logic and conveniently matches the physical position of the footswitch)
int footswitch_press_count = 0;
int64_t footswitch_start_time = 0;
int64_t footswitch_last_press_time = 0;
bool footswitch_long_press_triggered = false;
esp_timer_handle_t single_press_timer;

// struct Button footswitchButton;
// PressEvent footswitch_btn_state;

//
// Local Function Declarations
//
void configure_gpio_pins();
void handle_button_press();
void ensure_relay_state();
void handle_single_press(void *param);
void handle_double_press(void *param);
void handle_long_press(void *param);
void single_press_timer_callback(void* arg);
void start_single_press_timer();
void cancel_single_press_timer();

void gpio_task(void *pvParameter) {
    ESP_LOGI(TAG, "GPIO task started");
    configure_gpio_pins();

    // double last_time = 0.0;

    while(1) {
        handle_button_press();
        ensure_relay_state();

        // int64_t time_us = esp_timer_get_time(); // Get time in microseconds
        // double time_ms = time_us / 1000; // Convert to milliseconds
        // double time_seconds = time_us / 1000000;    // Convert to seconds
        // if ((int)time_seconds % 2 == 0 && (int)time_seconds != (int)last_time) {
        //     ESP_LOGI(TAG, "Time: %f", time_seconds);
        //     last_time = time_seconds;

        //     int current_footswitch_state = gpio_get_level(FOOT_SWITCH_GPIO);
        //     ESP_LOGI(TAG, "Footswitch State: %d", current_footswitch_state);
        // }

        vTaskDelay(pdMS_TO_TICKS(50)); // Small delay for debouncing
    }
    vTaskDelay(portMAX_DELAY);
}

void configure_gpio_pins() {
    // Configure the Footswitch GPIO as an input pin
    gpio_reset_pin(FOOT_SWITCH_GPIO);
    gpio_config_t foot_switch_gpio_conf = {
        .pin_bit_mask = (1ULL << FOOT_SWITCH_GPIO),
        .mode = GPIO_MODE_INPUT,
        .pull_up_en = GPIO_PULLUP_ENABLE,   // Enable internal pull-up resistor
        .pull_down_en = GPIO_PULLDOWN_DISABLE,
        .intr_type = GPIO_INTR_DISABLE      // Disable interrupt for this pin
    };

    gpio_config(&foot_switch_gpio_conf);

    // Configure the bypass relay GPIO as an output pin
    gpio_reset_pin(BYPASS_RELAY_GPIO);
    gpio_config_t relay_gpio_conf = {
        .pin_bit_mask = (1ULL << BYPASS_RELAY_GPIO),
        .mode = GPIO_MODE_OUTPUT,
        .pull_up_en = GPIO_PULLUP_DISABLE,
        .pull_down_en = GPIO_PULLDOWN_DISABLE,
        .intr_type = GPIO_INTR_DISABLE
    };

    gpio_config(&relay_gpio_conf);

    // Configure the bypass type GPIO as an output pin
    gpio_reset_pin(BYPASS_TYPE_RELAY_GPIO);
    gpio_config_t bypass_type_gpio_conf = {
        .pin_bit_mask = (1ULL << BYPASS_TYPE_RELAY_GPIO),
        .mode = GPIO_MODE_OUTPUT,
        .pull_up_en = GPIO_PULLUP_DISABLE,
        .pull_down_en = GPIO_PULLDOWN_DISABLE,
        .intr_type = GPIO_INTR_DISABLE
    };
    gpio_config(&bypass_type_gpio_conf);

    // TODO: Read the initial state of the foot switch. If it's a 0, that means
    // the user had it pressed at power up and we may want to do something
    // special.

    // Make sure the relays start out as off
    gpio_set_level(BYPASS_RELAY_GPIO, 0); // Turn off the relay GPIO
    current_bypass_relay_level = 0;
    gpio_set_level(BYPASS_TYPE_RELAY_GPIO, 0);
    current_bypass_type_relay_level = 0;
    ESP_LOGI(TAG, "GPIO Pins Configured");
}
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

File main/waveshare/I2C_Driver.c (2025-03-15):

#include "I2C_Driver.h"

#include "esp_err.h"

#define I2C_TRANS_BUF_MINIMUM_SIZE     (sizeof(i2c_cmd_desc_t) + \
                                        sizeof(i2c_cmd_link_t) * 8) /* It is required to have allocate one i2c_cmd_desc_t per command:
                                                                     * start + write (device address) + write buffer +
                                                                     * start + write (device address) + read buffer + read buffer for NACK +
                                                                     * stop */
static const char *I2C_TAG = "I2C";
/**
 * @brief i2c master initialization
 */
i2c_master_bus_handle_t i2c_bus_handle = NULL;

static esp_err_t i2c_master_init(void)
{
    i2c_master_bus_config_t bus_config = {
        .clk_source = I2C_CLK_SRC_DEFAULT,
        .i2c_port = I2C_MASTER_NUM,
        .scl_io_num = I2C_SCL_IO,
        .sda_io_num = I2C_SDA_IO,
        .glitch_ignore_cnt = 7,
        .intr_priority = 1,
        .flags.enable_internal_pullup = true,
    };

    esp_err_t ret = i2c_new_master_bus(&bus_config, &i2c_bus_handle);
    if (ret != ESP_OK) {
        ESP_LOGE(I2C_TAG, "Failed to create I2C master bus: %s", esp_err_to_name(ret));
    }
    return ret;
}
void I2C_Init(void)
{
    /********************* I2C *********************/
    ESP_ERROR_CHECK(i2c_master_init());
    ESP_LOGI(I2C_TAG, "I2C initialized successfully");  
}


// // Reg addr is 8 bit
// esp_err_t I2C_Write(uint8_t Driver_addr, uint8_t Reg_addr, const uint8_t *Reg_data, uint32_t Length)
// {
//     uint8_t buf[Length+1];
    
//     buf[0] = Reg_addr;
//     // Copy Reg_data to buf starting at buf[1]
//     memcpy(&buf[1], Reg_data, Length);
//     return i2c_master_write_to_device(I2C_MASTER_NUM, Driver_addr, buf, Length+1, I2C_MASTER_TIMEOUT_MS / portTICK_PERIOD_MS);
// }



// esp_err_t I2C_Read(uint8_t Driver_addr, uint8_t Reg_addr, uint8_t *Reg_data, uint32_t Length)
// {
//     return i2c_master_write_read_device(I2C_MASTER_NUM, Driver_addr, &Reg_addr, 1, Reg_data, Length, I2C_MASTER_TIMEOUT_MS / portTICK_PERIOD_MS);
// }

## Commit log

2025-02-05 Switch the backlight control frequency from 5kHz to 30kHz to avoid noise (#49)
    [defines.h]
2025-02-07 Use a foot switch to navigate user settings (#51)
    * Add partial implementation of controlling settings with FS
    This fix passes foot switch presses on to the gui task and
    also to the User Settings. You can now advance through menu
    settings with a single press.
    Still left to be done is supporting double-press to send a
    press event to a button.
    Long press when in tuning mode to activate user settings.
    * Implement the double-press so it works in user settings
    * Support double-press only in settings
    This keeps the normal press fast when switching between tuning and
    true bypass mode.
    * Set the backlight to 0% in true bypass mode
    * Use LVGL group for focused navigation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
    [defines.h, gpio_task.cpp, main.cpp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]
2025-02-10 Add q signal conditioner and a median filter for smoother tuning output (#54)
    * Add a median filter to the frequency output to smooth it a little
    * Enable the qLib signal conditioner on the input
2025-02-23 Add a new tuning UI called "Attitude" (like an airplane's Attitude Indicator) (#60)
    * Make the correct version show up on the About screen
    * Add a new tuner UI called "Attitude" (Attitude Indicator)
    Also:
    - Bumped the cents and frequency labels to 18pt (from 14pt)
    - Fixed an issue that was making the UI jump around (disabled
    scrolling on the main screen)
    [user_settings.cpp]
2025-03-05 Use the right GPIO for the momentary switch
2025-03-06 Bump to v2.0.0 in prep for switching to the EBD4 Waveshare
2025-03-15 Switch to Waveshare ESP32-S3 Touch 2.8" (240x320) (#63)
    * Add new tuner UI that's a note quiz
    * Use the right GPIO for the momentary switch
    * Update the web installer helper script
    * Bump to v1.0.7
    * Improve the note quiz tuning display
    * Bump to v2.0.0 in prep for switching to the EBD4 Waveshare
    * Initial stab at switching Waveshare ESP32-S3-Touch-LCD-2.8B (EBD4)
    * Use larger fonts on the Needle tuner
    * Use larger fonts on the Strobe tuner
    * Rework strobe tuner UI to work with EBD4
    * Switch the font files to a format that's closer to RGB565
    * Use DMA for the graphics buffers
    * Move timer handler *after* doing all LVGL work in the loop
    Also change the lcd to use 2 buffers. I thi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
    [partitions.csv]
2025-03-15 Switch to ADC2_CH7 (GPIO18) because GPIO15 is a strapping pin according to ESP32 tech ref
2025-03-17 Comment out some debug output printing
2025-03-18 Adjust the noise floor value
    [defines.h]
2025-03-19 Fix use of 1EU filter and also improve general smoothing
    A frequency is no longer reported to the UI unless a target note
    is seen more than once in a row. This helps prevent too much
    jumping around in the UI.
    I also messed around with the 1EU filter for getting the UI to
    feel more smooth. Right now pitch detection is using two 1EU filters
    and a moving average to smooth the detected frequency.
    Signal > Pitch Detector > 1EU Filter > Moving Avg > 1EU Filter > UI
    [defines.h, gpio_task.cpp, main.cpp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]
2025-03-19 Fix attitude tuner and use exp smoother too
    Also adds an additional demo video and turns off the LVGL perf info.
    [defines.h, pitch_detector_task.cpp]
2025-03-25 Add support for the buffer type relay (true/buffered bypass) (#67)
2025-04-01 Unmute inside bypass type settings screen
    This makes it so you can hear the difference more easily when switching
    between buffered bypass and true bypass mode without having to exit the
    settings screen.
2025-04-03 Keep bypass type correct when turning on/off monitoring mode (#71)
    This also moves the UserSettings into a static reference (extern)
    variable instead of passing it all around in all the callbacks.
    [user_settings.cpp]
2025-04-13 Modify the double press and long press behavior in settings (#72)
    Long press now activates the focused button. Double press moves the
    focus to the previous item in the focus group. When you exit a screen
    it will automatically focus the Back/Exit button as a convenience.
2025-04-13 Prevent a crash when setting note name after switching to bypass
    If you were playing a note, switched to bypass mode (screen turns
    off) and then the note stopped playing, the timer to fade the note
    to none was firing on the UI that was already deleted from memory.

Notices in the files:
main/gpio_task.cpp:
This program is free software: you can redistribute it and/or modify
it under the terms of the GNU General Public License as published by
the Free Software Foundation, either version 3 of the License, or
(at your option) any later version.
